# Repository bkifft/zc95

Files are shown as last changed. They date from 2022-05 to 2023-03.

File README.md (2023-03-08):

# ZC95

## Introduction
The ZC95 is a DIY four channel EStim box with similar form factor & output design to the MK312-BT (which in turn is a clone of the ET-312B).
Unlike the 312B, it uses 2x Raspberry Pico microcontrollers instead of an ATMEGA16, and the firmware is open source and mostly written in C++.

If a Pico-W is used for the main MCU, it can be controlled remotely via a Python GUI, and run Lua scripts uploaded to it.

Compared to an MK312-BT, it has 2 extra channels, two trigger inputs (think predicament bondage), and an accessory port. It is missing bluetooth and, _so far_, most of the patterns of the 312. Audio input is possible with an extra/optional board.

Additionally, if a 433MHz transmitter is fitted it can be used to control certain types of shock collars from some patterns.

It's mostly built using through hole parts, with one PCB being mostly SMD - but using parts available through the JLCPCB SMT assembly service. The only exception to this is the ADC for the front panel which is a SOIC-16 footprint so should still be easy enough for most to solder.

### Assembled ZC95
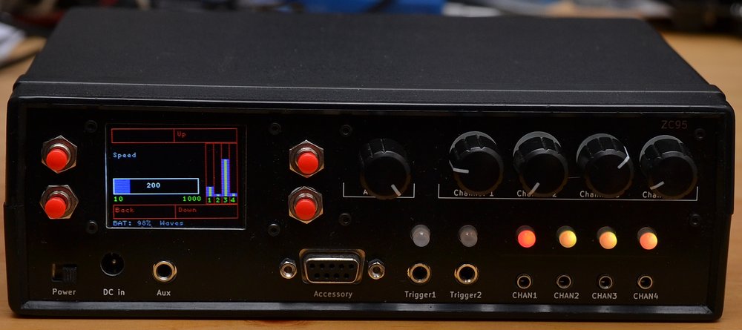
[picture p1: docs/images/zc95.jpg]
zc95


## Overview
The ZC95 consists of 4-5 PCBs:

* Front panel - no traces, just text / mounting holes
* Front panel controls - 4x POTs and associated ADC, 1x rotary encoder and 6 serial RGB LEDs
* Main board - power supply / charging, MCU for display / pattern generation, button input etc
* Output board ("ZC624 Output module") - 4 channel output generation controlled via SPI from the main board. Designed for production using the SMT assembly service at JLCPCB, with a handful of extra through hole parts also requiring hand soldering.
* (Optional) audio input board - allows the 3.5mm "Aux" port on the front panel to be used for audio input

The primary reason for having separate PCBs for the main and output board is for future flexibility - most of the time & expense is the firmware, case, display, controls, etc., so being able to test new output designs whilst being able to keep all of that should be an advantage. I'm well aware the output design currently used is known to have flaws, mostly stemming from its lack of feedback (which applies equally to the 312b it was taken from). A challenge for another day.

## [Build guide](docs/Build.md)

## [Schematics](schematics/)

## [Gerbers](pcb/)

## [Compiled firmware](https://github.com/CrashOverride85/zc95/releases/)

## [Operation notes](docs/Operation.md)

## [Pattern guide](docs/Patterns.md)

## [Lua scripting notes](docs/LuaNotes.md)

## [Credits](docs/Credits.md)

# TODO
## Firmware
   - Combo pattern? Having, e.g., waves on channels 1+2 plus something like TENS on 3+4 would be good
   - Save pattern settings on exit?

## Hardware
   - Maybe a better power switch? although still being able to get all the parts for the main board from LCSC is good
   - Low battery shutoff

## Long term road map
May do some of this, all of this, or none of this!
   - Combine main, output and audio boards into one, and probably switch to almost all SMD so it can be assembled by JLCPCB
   - Probably remove "Aux" socket and swap for separate "Serial" and "Audio" sockets
   - Use a lithium battery pack instead of a 12v SLA
   - Use a USB charger
   - Maybe a smaller, 3D printed case. Probably keeping the same width/weight though

## Known issues
   - Battery gauge is pretty hopeless
   - Depending on the pattern, the LEDs aren't very useful - either Red or Green, with no dimming depending on power

[zc95]: docs/images/zc95.jpg "Assembled ZC95"

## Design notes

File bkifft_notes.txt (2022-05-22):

made changes:
- used max232 with its 1 uF charge pumps

planned changes:
- use mk312 buttons
- change 12V rail to 13.3 V to use a 3s?p liion battery

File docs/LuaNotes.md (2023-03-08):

# Lua

## Capability
Lua scripts can be written / uploaded (see [Remote Access](./RemoteAccess.md) for how to upload) to add new patterns to the ZC95. These scripts are able switch each channel on/off, set the frequency and pulse width, and set the power level (scaled to what the front panel is set to - i.e. a Lua script can't set the output power to higher than set on the front panel).
They can also receive notification of settings being changed via the menu, and inputs from the external trigger inputs along with the top left soft button being pressed.
The most significant thing they can't do (that inbuilt patterns can) right now is anything to do with audio.

## Example scripts
There are a few example scripts in `remote_access/lua`, which demonstrate some of things that can be done from Lua. These scripts are:

* fire.lua - If the soft button is pressed, all channel's are activated for as long as the button is held down. If any of the 4 external triggers (assuming stereo connectors are being used), the the corresponding channel (1-4) is activated for as long the trigger is active.

* toggle.lua - switches between channel 1+2 & 3+4 at a speed that can be set via the menu. If the channels are switched on constant or just pulsed can also be set from the menu

* waves.lua - a waves pattern that is slightly more advanced than the inbuilt one. For each channel, this varies the frequency between 25Hz and 250Hz and the pulse width between 40us and 200us, with the time taken for each cycle being set per channel on the menu.

## toggle.lua

It's probably easier to explain Lua as implemented in the ZC95 by going though one of the example scripts.

toggle.lua:
```
_delay_ms = 500

Config = {
    name = "Toggle",
    menu_items = {
        {
            type = "MIN_MAX",
            title = "Delay",
            id = 1,
            min = 100,
            max = 2000,
			increment_step = 100,
            uom = "ms",
			default = _delay_ms
         },
         {
            type = "MULTI_CHOICE",
            title = "Output",
            id = 2,
            choices = {
                {choice_id = 1, description = "Pulse"},
                {choice_id = 2, description = "Constant"}
            }
         }
    }
}

_channel12_on = false
_wait_until_ms = 0
_pulse_mode = true

function MinMaxChange(menu_id, min_max_val)
    if (menu_id == 1)
    then
        _delay_ms = min_max_val
    end
end

function MultiChoiceChange(menu_id, choice_id)
    if (menu_id == 2 and choice_id == 1)
    then
        _pulse_mode = true
    end

    if (menu_id == 2 and choice_id == 2)
    then
        _pulse_mode = false
    end
end

function Loop(time_ms)
    if (time_ms > _wait_until_ms)
    then
        ToggleChannel();
        _wait_until_ms = time_ms + _delay_ms
    end
end

function ToggleChannel()
    if (_channel12_on == true)
    then
        zc.ChannelOff(1)
        zc.ChannelOff(2)

        if (_pulse_mode == true)
        then
            zc.ChannelPulseMs(3, 100)
            zc.ChannelPulseMs(4, 100)
        else
            zc.ChannelOn(3)
            zc.ChannelOn(4)
        end
        _channel12_on = false
    else
        if (_pulse_mode == true)
        then
            zc.ChannelPulseMs(1, 100)
            zc.ChannelPulseMs(2, 100)
        else
            zc.ChannelOn(1)
            zc.ChannelOn(2)
        end

        zc.ChannelOff(3)
        zc.ChannelOff(4)
        _channel12_on = true
    end
end
```

The `Config` section is used to set the name and build the on screen menu:
```
Config = {
    name = "Toggle",
    menu_items = {
        {
            type = "MIN_MAX",
            title = "Delay",
            id = 1,
            min = 100,
            max = 2000,
			increment_step = 100,
            uom = "ms",
			default = _delay_ms
         },
         {
            type = "MULTI_CHOICE",
            title = "Output",
            id = 2,
            choices = {
                {choice_id = 1, description = "Pulse"},
                {choice_id = 2, description = "Constant"}
            }
         }
    }
}
```
`name = "Toggle"` sets the name for the script - this is prefixed with `U:` then used on the patterns menu.

A menu entry is displayed when the script is running for each item in `menu_items`; each must be given a unique id, numbered sequentially from 1. There are two types supported:
* `MIN_MAX` - shows a horizontal bar graph that can be changed between the set min/max using the adjust dial. The unit of measure (uom) text is displayed as suffix to the numeric value in the bar chart 
* `MULTI_CHOICE` - used to show a menu option that allows for one of multiple settings to be picked. Each choice must have a unique id.

```
function MinMaxChange(menu_id, min_max_val)
    if (menu_id == 1)
    then
        _delay_ms = min_max_val
    end
end
```
If present, the `MinMaxChange(menu_id, min_max_val)` function is called whenever a `MIN_MAX` menu type is changed, with the ID of the menu and the new value.

```
function MultiChoiceChange(menu_id, choice_id)
    if (menu_id == 2 and choice_id == 1)
    then
        _pulse_mode = true
    end

    if (menu_id == 2 and choice_id == 2)
    then
        _pulse_mode = false
    end
end
```
Similar to MinMaxChange but for `MULTI_CHOICE` menu types; if present, the `MultiChoiceChange(menu_id, choice_id)` function is called whenever a `MULTI_CHOICE` type menu entry is changed, with the menu ID and the choice ID now selected.

```
function Loop(time_ms)
    if (time_ms > _wait_until_ms)
    then
        ToggleChannel();
        _wait_until_ms = time_ms + _delay_ms
    end
end
```
The `Loop(time_ms)` function is mandatory, and is called periodically for as long as the Lua script is running. The time_ms parameter is how long, in milliseconds, since the box was powered up.

```
function ToggleChannel()
    if (_channel12_on == true)
    then
        zc.ChannelOff(1)
        zc.ChannelOff(2)

        if (_pulse_mode == true)
        then
            zc.ChannelPulseMs(3, 100)
            zc.ChannelPulseMs(4, 100)
        else
            zc.ChannelOn(3)
            zc.ChannelOn(4)
        end
        _channel12_on = false
    else
        if (_pulse_mode == true)
        then
            zc.ChannelPulseMs(1, 100)
            zc.ChannelPulseMs(2, 100)
        else
            zc.ChannelOn(1)
            zc.ChannelOn(2)
        end

        zc.ChannelOff(3)
        zc.ChannelOff(4)
        _channel12_on = true
    end
end
```

The `ToggleChannel()` function (could have been named anything) is switching between the two pairs of channels. The relevant parts are the zc.* functions:
* `zc.ChannelPulseMs(channel, duration)` - will pulses a channel on for the specified number of milliseconds
* `zc.ChannelOn(channel)` - switches a channel on until switched off
* `zc.ChannelOff(channel)` - switches a channel off

See zc.* functions section below for more details along with all available zc.functions

## zc.* functions
Functions that can be called from Lua scripts to control the box. In addition to these, `print("<whatever>")` can be used from scripts (no `zc.` prefix); the output will appear in the serial output prefixed with '`[LUA]`', and in the debug window of the `pattern_gui.py` GUI if running remotely. 

### SetPower
```
Params:
    * channel - 1-4
    * power   - 0-1000
```
Sets the output power of channel from 0 to 1000. This output power is scaled based on what the front panel dial is set to for the channel. E.g if the front panel is set to 50% and a power level of 500 is set, the result will be a power level of 250 (25%).

If there is no `Setup()` function in the script, all channels will default to full power (i.e. only affected by front panel dials), so it often isn't necessary to use this. Most inbuilt patterns don't change the power level.

### SetFrequency
```
Params:
    * channel number (1-4)
    * frequency (1 - 300) Hz
```
Sets the output frequency of the specified channel. Currently defaults to 150Hz, but this default may move into the config menus at some point.

### SetPulseWidth
```
Params:
    * channel number (1-4)
    * positive pulse width (1-255) us
    * negative pulse width (1-255) us
```
Sets the pulse width used for the channel, defaults to 150us, but this default may move into the config menus at some point.
For symmetric pulses (as used by most/all inbuilt patterns), these two values should be the same. 

### ChannelPulseMs
```
Params:
    * channel number (1-4)
    * duration (ms)
```
Switch the channel on for the specified number of milliseconds, using the previously set frequency, pulse width and power level (or the defaults, if not changed).

### ChannelOn
```
Params:
    * channel number (1-4)
```
Switch on the specified channel, until ChannelOff is called, using the previously set frequency, pulse width and power level (or the defaults, if not changed).

### ChannelOff
```
Params:
    * channel number (1-4)
```
Switch off the specified channel.

## Special functions
These are functions that will be automatically called when applicable whilst the Lua script is running. With the exception of `Loop()`, all are optional. 

### MinMaxChange(menu_id, new_value)
Called when a `MIN_MAX` type pattern option is changed, and is called with the menu ID of the option, and the new value (which should lie between the min and max configured).

### MultiChoiceChange(menu_id, choice_id)
Called when a `MULTI_CHOICE` type pattern option is changed, and is called with the menu ID of the option, and the ID of the selected choice.

### SoftButton(pushed)
Called with `pushed=True` when the top left soft button is pressed, and then again when it is released with `pushed=False`.

### ExternalTrigger(socket, part, active)
Called when an external trigger happens.

Socket: can be either "`TRIGGER1`" or "`TRIGGER2`" for the Trigger1 and Trigger2 sockets respectively. 

Part: can be either "`A`" or "`B`". With a stereo 3.5mm TRS cable inserted, shorting Tip and Sleeve is part `A` (trigger LED lights up green). Shorting Tip and Ring is part `B` (trigger LED lights up red). When triggered, `active` will `True`, when released it will be `False`.

### Setup
Called once when the pattern is started, before `Loop()`. It can be used to do any initial setup, including setting power level. If this function does _not_ exist, the power level is defaulted to 1000, otherwise it is set to 0 and can be set to something more appropriate here. 

### Loop(time_ms)
Called periodically for as long as the pattern is running. `time_ms` is how long in milliseconds the box has been powered on.

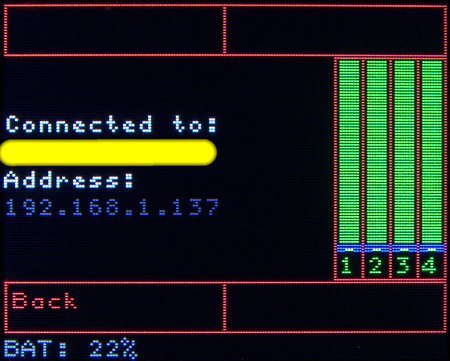
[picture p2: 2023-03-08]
docs/images/screen_ra_connected.jpg

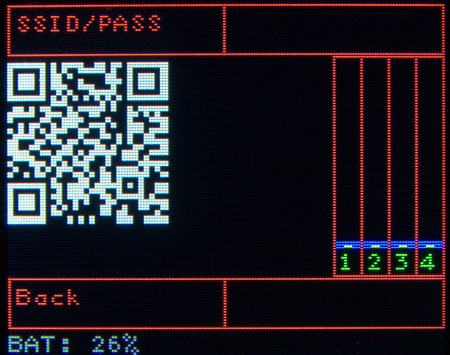
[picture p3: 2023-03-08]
docs/images/screen_ra_qr.jpg

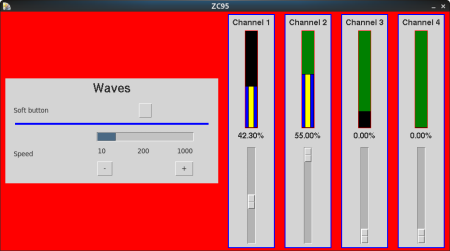
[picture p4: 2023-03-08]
docs/images/pattern_gui_start.png

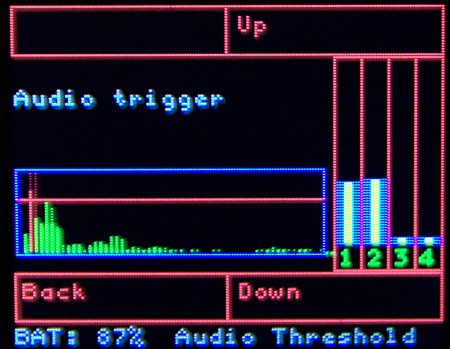
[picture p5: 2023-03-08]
docs/images/screen_pattern_audioThreshold.jpg

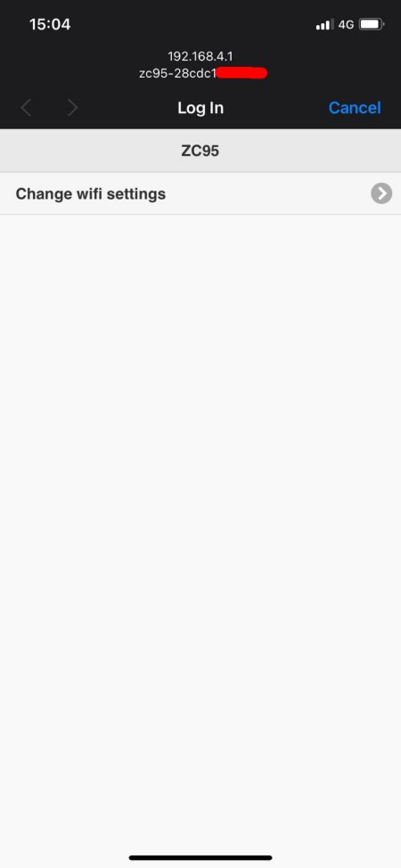
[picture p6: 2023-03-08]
docs/images/phone_config_wifi.jpg

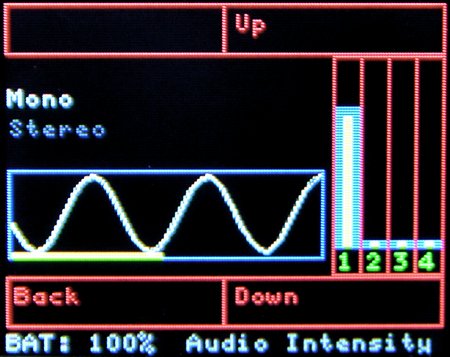
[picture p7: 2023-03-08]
docs/images/screen_pattern_audioIntensity.jpg

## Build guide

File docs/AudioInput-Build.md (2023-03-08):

# Hardware build notes for audio input board

## Changes to ZC95 main board
Two changes are required:
  1. Remove the jumpers on J8
  2. Fit a 10 way 2.54mm pin header on J17

## Ordering
Parts required for this board are on the "Audio input" tab of the [BoM (openoffice format)](BoM.fods) spreadsheet. 
When building the board, there are two choices for gain control:

1. Internal adjustment only - fit RV1 and RV2
2. (Recommended) Variable from menu - Fit U1. Also allows the presence of the board to be auto-detected

The downside of fitting U1 is cost, plus it's an SMD part (and whilst not hard, it's also not the easiest part to solder if you've never done anything SMD before). Also it's the sort of part that might go out of stock at any moment...

Order the blank PCB from JLC using the [AudioInput](../pcb/AudioInput.zip) gerbers and the default settings (FR-4, 1.6mm thick, 1oz, etc.)

## Assembly notes

Unfortunately I didn't manage to fit the component values on the silkscreen, so the best way to assemble the board is probably just going through the BoM which lists component references & values; a printout of the [board outline and silkscreen](./AudioOutput.pdf) may help.

Mistake on silkscreen: the footprints for Q1 & Q3 (P Channel MOSFETs) are backwards if ordering the LCSC part C151450. If ordering the part from elsewhere be aware that BS250 MOSFETs come in two different pinouts - DGS and SGD, so putting the part in backwards is rather easy! Perhaps a poor choice of mosfet by me there.
The most practical solution is probably just to use a diode tester on the actual part, and put the anode on the left when inserting it (assuming the board is orientated with the version text the right way up at the bottom).

Assembled board:

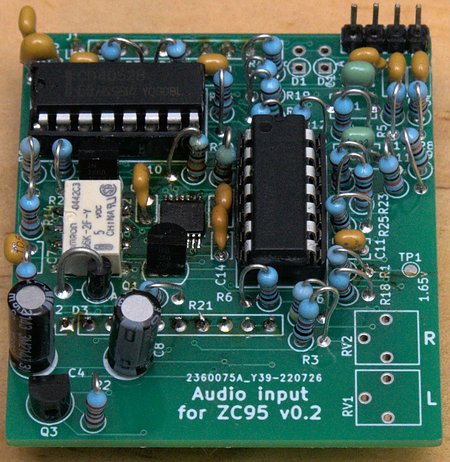
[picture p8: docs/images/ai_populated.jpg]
AI board


Once assembled, plug the audio board into the main board, with the text ("Audio input for ZC95") towards the front / near the front panel. Be careful to line it up correctly with the headers, it is possible to insert it misaligned. 

If the digipot was fitted (U1) it should "just work", and the audio pattern(s) and "Audio input" menu should appear. If it wasn't fitted use the hardware config menu (see [audio operation notes](./AudioInput-Operation.md)) to set the Audio to "On (no gain)".

## Brief description
Hopefully not needed for the assembly & use of the board, but maybe a few notes about what this board is doing is good idea.

Without the board fitted, the jumpers fitted to J8 on the main board send the RS232 output from the UT232A IC to the 3.5mm "Aux" socket on the front panel. With the board fitted, the relay can be used to switch the Aux socket between the UT232A, and (ultimately) the ADC inputs present on header J1.

This somewhat shoddy diagram shows a high level overview of what's going on:

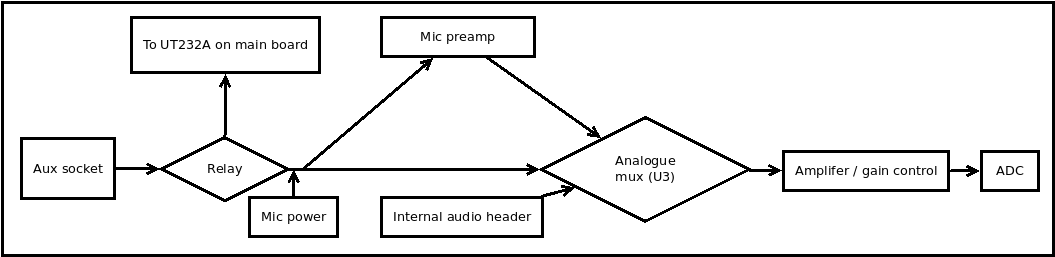
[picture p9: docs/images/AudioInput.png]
AI diagram


The firmware uses the presence of the digipot (U1, used for gain control) to detect the board and show the audio options. But this can be overridden from the Hardware Config menu, see [audio operation notes](./AudioInput-Operation.md).

One more thing maybe worthy of note is microphones... as this is an area where I didn't know what I didn't know!

There seem to be two common types of microphones (ignoring expensive stuff):

1. Electret microphones - typical PC style mics, including lavalier mics. These either require a small amount of power supplied to operate (in the region of 2v - 5v), or are self powered and need batteries / charging. Google suggests that electret mics generally have this bias power power on the ring, with signal on the tip. But of the two I tested, they both needed power on the tip. So like the mk312bt, this board also supplies power on tip+ring when enabled. There seem to be a few pinouts to consider when you get into stereo mic inputs, combined headset + mic inputs (4 conductor jacks), etc.

2. Dynamic microphones - think a hand held karaoke mic, that sort of thing. Produce a weaker signal than electret mics, but require no power (**and power could damage them**). Typically have a 6.35mm jack, but not always.

This audio input board works best with electret mics - there's not quite enough gain for dynamic mics - although R9 & R10 in the mic preamp could almost certainly be adjusted to make them work well enough.

[AI board]: images/ai_populated.jpg "Assembled audio input board"
[AI diagram]: images/AudioInput.png "Audio input diagram"

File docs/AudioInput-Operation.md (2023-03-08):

# Audio Input

If the (optional) audio input board is present, an extra "Audio input" option shows on the settings menu, along with patterns using audio input.

Audio input can be either line level or mic level (selectable), and optionally power can be provided for mics. It's intended to be used with PC style electret microphones. I've found this microphone works particularly well (and with the mk312bt): https://www.amazon.co.uk/gp/product/B07L6H7YYQ/

When the audio input board is installed, the Aux port on the front can be configured for either Audio input (default) or serial I/O (currently only debug out).

## Configuration
There are two relevant menus for configuring audio - "Audio input" and "Hardware config" ("Audio" and "Aux port use").

### Audio input
This is used to set gain, enable/disable microphone preamp (so set for mic or line level), enable/disable microphone power, and show a preview of the audio signal to aid setting volume and gain.
The configuration set here will be used in patterns, and will be retained after power off. 

On opening the screen, it should show the currently configured settings. E.g.:

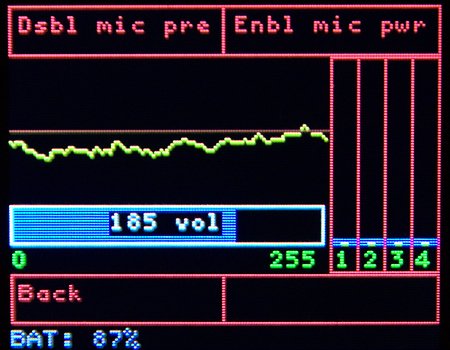
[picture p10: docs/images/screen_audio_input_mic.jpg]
Audio input mic


The above screenshot is when in microphone mode, with the microphone power disabled (using a self powered electret mic). Options:
* Ddbl mic pre: Disable microphone preamp - i.e. switch to line level input
* Enbl mic pwr: Enable microphone power - provide power for an unpowered electret microphone. Note this should not be used with dynamic mics or when connected to a line level output

Disabling the mic preamp switches to line level input, and shows stereo input:

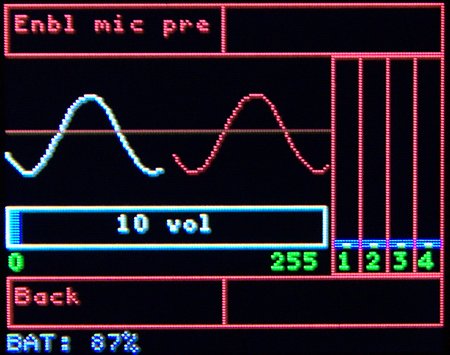
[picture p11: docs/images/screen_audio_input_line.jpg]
Audio input line


### Hardware config
There are two relevant entries in the hardware config menu:

1. Audio. 
This is used to control audio functionality, and has 3 options
    - Auto - Default. If the audio output board is detected (specifically, if the MCP4651 digital potentiometer is found), then audio functionality is enabled, otherwise it's hidden.
    - On (no gain) - Audio input functionality is enabled regardless of the audio board being detected or not. But the gain/volume option is removed, as that requires the digital potentiometer to be present.
    - Off - hide audio functionality even if audio input board found

2. Aux port use. 
With the audio board present, the zc95 has the ability to switch the use of the port between serial I/O and audio input. At present, the only use for the serial option is outputting debugging info, but in the future some patterns may make use of it. Two options:
    - Audio input - Default. Port is used for audio input
    - Serial I/O - port is used for serial I/O

Note this option has no effect if the audio input board isn't present; the port is always routed to the serial interface.

[Audio input mic]: images/screen_audio_input_mic.jpg "Audio input configuration screen - mic"
[Audio input line]: images/screen_audio_input_line.jpg "Audio input configuration screen - line input"

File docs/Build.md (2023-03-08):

# Hardware build notes 

*Disclaimer*: These instructions are complete to the best of my knowledge, however I've only built the one so far, and that was over quite some time, so there may be omissions.

There is now an optional audio [input board](./AudioInput-Build.md) too.

## Prerequisites 
These notes assume a reasonable amount of experience assembling electronic kits. Other than through hole soldering, it also requires:
* Soldering 1 SMD part on the front panel control board. This is a SOIC-16 package, so fairly large / easy to solder
* Creating an IDC cable
* Crimping connectors for Molex KK style (well, clones in this case) connectors. Other 2.54mm connectors could be substituted.

## PCB + Parts ordering
### PCBs
For these 3 boards, order from JLC using the linked gerbers and default settings (FR-4, 1.6mm thick, 1oz, etc.) except where noted:
* [Front panel](../pcb/FrontPanel.zip). Suggest ordering in black
* [Front panel controls](../pcb/FrontPanelControls.zip). Set "Remove Order Number" to "Specify a location" (location is already specified on the back of this board)
* [Main board](../pcb/MainBoard.zip)

The output board ("ZC624 Output module") has been designed with the JLCPCB SMT assembly service in mind, although the footprints are the hand-solder versions where applicable, and some (through hole) parts still need hand assembly.
Order the board using [these gerbers](../pcb/OutputModule/OutputBoard-gerbers.zip) and the default options as per the other boards.

This time, select the "SMT Assembly" option at the bottom - pick "Assemble top side" and Tooling holes "Added by JLCPCB". 
On the next page, add the BOM and CPL files:
* [output_bom_jlc.csv](../pcb/OutputModule/output_bom_jlc.csv)
* [output_cpl_jlc.csv](../pcb/OutputModule/output_cpl_jlc.csv)

The next page should show a list of all parts found / matched. Deselect the SS210 component (D8, D9, D10, D11, D12, D13, D14, D15), these aren't needed and reduce output power.

### PCB Parts
All parts required to populate the PCBs - with the exception of the transformers - can be purchased from LCSC, and this BOM spreadsheet lists required parts + quantity with the LCSC part number for each board on separate tabs:

[BoM (openoffice format)](BoM.fods)

As with the MK312-BT, the PFETs (IRF9Z24NPBF) in particular should not be substituted with anything similar, the exact part should be used.

### Misc parts
[The BoM spreadsheet](BoM.fods) includes a Misc tab with the rest of the parts required to complete the build (case, display, etc.).

## Assembly

### Main board
Photo of board as it arrived from JLCPCB:

main board

* Be sure not to mix up U3 (LM2941T, top left) and U6 (LM2576T-5, top middle), these have the same footprint and quite similar names
* Fit the IC sockets (if ordered) instead of directly soldering the ICs to the board
* J8 should have jumpers between pins 1+2, 3+4, 7+8, 9+10, like so:

  jumpers

  Without these the serial port on the front won't work (but it won't affect anything else).
* Solder short (~12cm or so) wires on to J13, and fit spade connectors on the other end for the battery
* R14 & D4 (top middle) don't need to be populated. It's for a power LED that has no place on the front panel.
* J20 (I2C header, bottom left) is for future expansion and doesn't need to be populated
* J17 (just below battery, to the right) is for the optional audio input board; if building that, fit a 2.54mm pin header, otherwise leave unpopulated

Then (optionally) plug a 433MHz transmitter into J11

Populated board:

main board populated

### Output board ("ZC624 Output module")
Photo of board as it arrived from JLCPCB:

zc624 smt only

D8-D15 are populated in this photo, but these should be omitted when ordering the boards (or removed if ordered by mistake), as they reduce output power.

Notes
* The pin headers J1, J2 & J3 go on the bottom of the board, J4 ("Serial") on the top. I found it easier to plug the board into the main board, then solder J1, J2 & J3 to be sure they were straight / lined up
* The 4 transformers have the "P" facing inwards (towards each other). Note that the transformers are used "backwards" - the side labelled primary goes to outputs.
* PFETs Q2, Q5 & Q8 should have the metal back facing towards the bottom (transformer end) of the board. Q11 is the other way round (silkscreen is correct)
* Solder on both the 1x20 pin sockets for the Pico. The 3 pin header on the right should be unpopulated.

Fully assembled board:

zc624 populated

### Front panel controls 
Photo of board as it arrived from JLCPCB:

front panel controls-bottom
front panel controls-top

* All resistors are 10k, with the exception of R29 which is 100R (R29 is also the only resistor with its value labelled)
* Getting the LEDs at the correct height can be a little awkward. Suggest soldering the POTs + rotary encoder first, putting the LEDs in (no solder yet), then attaching the board to the front panel (using 20mm bolts). Make sure the LEDs are level-ish, then solder in place.
* Stating the obvious, but put the parts on the side indicated by the silkscreen (LEDs, POTs and rotary encoder one side, the rest the other)
* J1 should have the cut-out facing towards SW5 (rotary encoder)

Fully assembled board:

front panel controls-bottom-populated
front panel controls-top-populated

### Front panel
Photo of board as it arrived from JLCPCB:

front panel

* Perhaps the most annoying part of the whole build is creating a cable for the 4 buttons. The buttons are named like so:

front panel buttons

Wire each button back to a connector in the position that matches the silkscreen (first two positions are button A, next two button B, etc.)
Then attach the buttons to the front panel.

* Attach connector to back of LCD, then LCD to the front panel with M2, 12mm bolts

The board should look something like this:

front panel back

Finally, attach the front panel controls board using 20mm bolts. The completed assembly should look something like:

front panel assembled

### Miscellaneous
* Create a 10pin F-F cable for the display:

10pin F-F cable

(ok, so that looks pretty messy, but it works)

* Create a 2x4 way IDC cable for the front panel controls to main board:

8w IDC

* Push the front panel (with controls board already attached) onto the main board, then screw on the DB9 socket:

front panel attached to main

* Slot the boards into the case, and screw in place: Screw Length (Excluding Head): 1/4" (6.5mm), Screw Size: No.6 (3.5mm)

* Stick the battery down. Suggest using 3M double sided tape (MNT-FT24MM-16FT)

* Connect front panel to main board using IDC cable

* Connect LCD to main board using 10pin cable

* Copy main board firmware onto first Pico, or a Pico W if wanting remote access (see section below), then plug into main board (USB socket pointing towards the left / nearest case edge)

* Copy ZC624 firmware onto second Pico (see section below), then plug into ZC624 board (USB socket pointing towards the left)

* Plug the ZC624 into the main board. Be careful to line it up correctly as it is possible to plug it in misaligned which would be bad

* Connect battery

Assembled ZC95 should look like:

zc95 assembled

### Loading firmware
Download firmware from [Releases](https://github.com/CrashOverride85/zc95/releases).

To load firmware onto a Pico:
* Hold down the BOOTSEL button
* Connect to PC via USB
* The Pico should appear as a USB mass storage device. Drag the appropriate uf2 firmware binary onto the drive:
  - zc95.uf2 - Main board firmware
  - OutputZc.uf2 - ZC624 firmware

And don't mix the two up!

### Power up
On power up, the LEDs should briefly turn purple (~2s), then turn green as the screen switches on and shows:

zc95 powered up

# Debugging
If any of the I2C devices aren't detected, you should see an error similar to the below:

hw check fail

Here, it can't find the two ICs on the front panel (in this case, the IDC cable was unplugged).
There is serial debugging output on the "Accessory" DB9 connector (tx pin 3, ground pin 5) on the front panel at RS232 levels.

There is also debugging output from the ZC624 board on the serial header. Note that is at 3v3 level, and RS232 levels would damage it. 

[jumpers]: images/jumpers.jpg "J8 with jumpers fitted"
[main board]: images/main_board.jpg "Unpopulated main board"
[main board populated]: images/main_board_populated.jpg "Populated main board"
[zc624 smt only]: images/zc624.jpg "ZC624 as received from JLCPCB"
[zc624 populated]: images/zc624_populated.jpg "Fully populated ZC624"
[front panel controls-bottom]: images/fpc_bottom.jpg "Unpopulated front panel controls board - bottom"
[front panel controls-top]: images/fpc_top.jpg "Unpopulated front panel controls board - top"
[front panel controls-bottom-populated]: images/fpc_bottom_populated.jpg "Populated front panel controls board - bottom"
[front panel controls-top-populated]: images/fpc_top_populated.jpg "Populated front panel controls board - top"
[front panel]: images/fp.jpg "Front panel"
[front panel buttons]: images/fp-abcd.jpg "Front panel with buttons labelled"
[front panel back]: images/fp_back.jpg "Back of front panel with LCD and buttons attached"
[front panel assembled]: images/fp_assembled.jpg "Front panel with LCD, buttons and controls attached"
[10pin F-F cable]: images/10pinFF.jpg "10 pin F-F cable"
[8w IDC]: images/8w_idc.jpg "2x4 IDC cable"
[front panel attached to main]: images/fp_attached_to_main.jpg "Front panel attached to main board"
[zc95 assembled]: images/assembled.jpg "Fully assembled ZC95, minus cover"
[zc95 powered up]: images/powered_up.jpg "Fully assembled ZC95 powered up"
[hw check fail]: images/hw_check_fail.jpg "Power up error"

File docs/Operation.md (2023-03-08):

# Operation

## Device layout
device layout

Buttons 1 - 4 are soft buttons and the purpose changes dependant on the screen. 

| Number | Description
| --- | ---
| 1 | Softbutton - Used to select pattern from the main menu, and changes dependant on the selected pattern.
| 2 | Softbutton - Usually back / return to previous screen
| 3 | Softbutton - Usually scroll up
| 4 | Softbutton - Usually scroll down
| 5 | Power. Left is off, right is on. Probably should have labelled that.
| 6 | Power in. Should be centre positive 15v DC
| 7 | Either Serial port, or if optional audio input board fitted, can be toggled between serial and audio input. In serial mode, Tip is TX / output from box, Sleeve is ground.
| 8 | Accessory port. Includes power, serial and 3x GPIO pins. See "Accessory port" in misc section. Currently not really used by much.
| 9 | Trigger input 1. Shorting either Sleeve or Ring to Tip registers trigger. The box can differentiate between S-T and R-T triggers (i.e. each trigger socket can react to two different inputs)
| 10 | Trigger input 2. As above, except currently unused.
| 11 | 2.5mm socket for channel 1 output
| 12 | 2.5mm socket for channel 2 output
| 13 | 2.5mm socket for channel 3 output
| 14 | 2.5mm socket for channel 4 output
| 15 | Adjust - Used to change the setting of on-screen sliders / multi choice options. A blue bar/background in the middle/left section of the screen indicates when the Adjust control can be used
| 16 | Power control for channel 1
| 17 | Power control for channel 2
| 18 | Power control for channel 3
| 19 | Power control for channel 4
| 20 | LED indicator for trigger 1. Lights up when triggered
| 21 | LED indicator for trigger 2. Lights up when triggered
| 22 | LED indicator for channel 1. Green = Internal channel 1 selected, but no output. Yellow = Shock collar 1 selected - see config section - but no output (2.5mm CHAN1 unused). Red = output on (either 2.5mm output or shock collar, depending on config)
| 23 | As above, but for channel 2 
| 24 | As above, but for channel 3
| 25 | As above, but for channel 4

## Screen
screen layout

| Number | Description
| --- | ---
| 1 | Softbutton - Text for softbutton 1
| 2 | Softbutton - Text for softbutton 2 
| 3 | Softbutton - Text for softbutton 3
| 4 | Softbutton - Text for softbutton 4
| 5 | Menu items. White text is the currently selected option
| 6 | Option corresponding to selected menu item. Can be changed using the Adjust dial
| 7 | Current power level for each channel. The blue bar represents the current maximum power the pattern can use, as set by the power control dials. The yellow bar inside it shows the current power level the patten is using. For most patterns, these will be the same, but some (e.g. triggered climb) will have a much smaller (but rising) yellow bar.

## On power up
On first power up, the box shows a menu of available patterns. Either the highlighted pattern can be started by pressing soft button 1, or the config menu can be entered by using soft button 2.

## Config
Configuration options so far:

* Remote access - Only visible if running on a Pico-W. Allows for remote access to the ZC95 over WiFi, for the purpose of either remotely controlling it or uploading Lua scripts. See [Remote Access](./RemoteAccess.md) 

* Channel config - For each channel 1-4, picks if either the internal output (on the 2.5mm connector) should be used, or if a shock collar should be triggered

* Collar config - Allows 4x shock collars to be configured. Each shock collar needs to be paired to the box, and the bottom option allows for testing the collar with the current settings. The "Chan." option corresponds to the CH button on the original remote, and it probably makes sense to be left as 1 for all collars, as each will have a unique ID anyway. Note that the mode (shock / vibrate / beep) needs to be set here, and won't change outside of this config screen (for the time being, at least)

* LED brightness - Pretty much what it says. If you value your eyesight, single digit values are good.

* Ramp up time - When starting a pattern, how long it takes to ramp up to the power level set for the channel on the front panel

* Audio input - Displayed if audio board present by default, depends on "Hardware config > Audio" setting. See [Audio Input](./AudioInput-Operation.md)

* Hardware config - configure various hardware settings. Shouldn't need changing. Options:
  - Audio - control display of audio options. See [Audio Input](./AudioInput-Operation.md) 
  - Debug output - where debugging information is sent:
    - Accessory port
    - Aux port
    - Off

    Note that if the Aux port is configured to be used for audio, picking Aux port here is essentially the same as "Off". Also worth noting that when the box is first powered up, debug info is always sent to the accessory port until the configuration is read, before potentially switching to aux or off.

  - Aux port use - what the Aux port on the front is used for. Options:
    - Audio input
    - Serial I/O

    If the audio board isn't present, this menu has no effect, i.e. Aux is always in Serial I/O mode.

* About - shows firmware version of main board, and zc624 output board

## Shock collars
If the box is fitted with a 433Mhz AM transmitter in J11 on the main board, it can be used to control one specific type of shock collar:

Shock collar

(note that there is 915MHz variant of these that looks identical on the outside...)

These will only function in certain patterns which have simpler output demands, and is generally pretty experimental.

[device layout]: images/layout.png "Device layout"
[screen layout]: images/screen.png "screen layout"
[shock collar]: images/shock_collar.jpg "Supported shock collar"

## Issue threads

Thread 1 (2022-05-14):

Missing i2c addresses in Frontpanel schematics

bkifft, 2022-05-14:

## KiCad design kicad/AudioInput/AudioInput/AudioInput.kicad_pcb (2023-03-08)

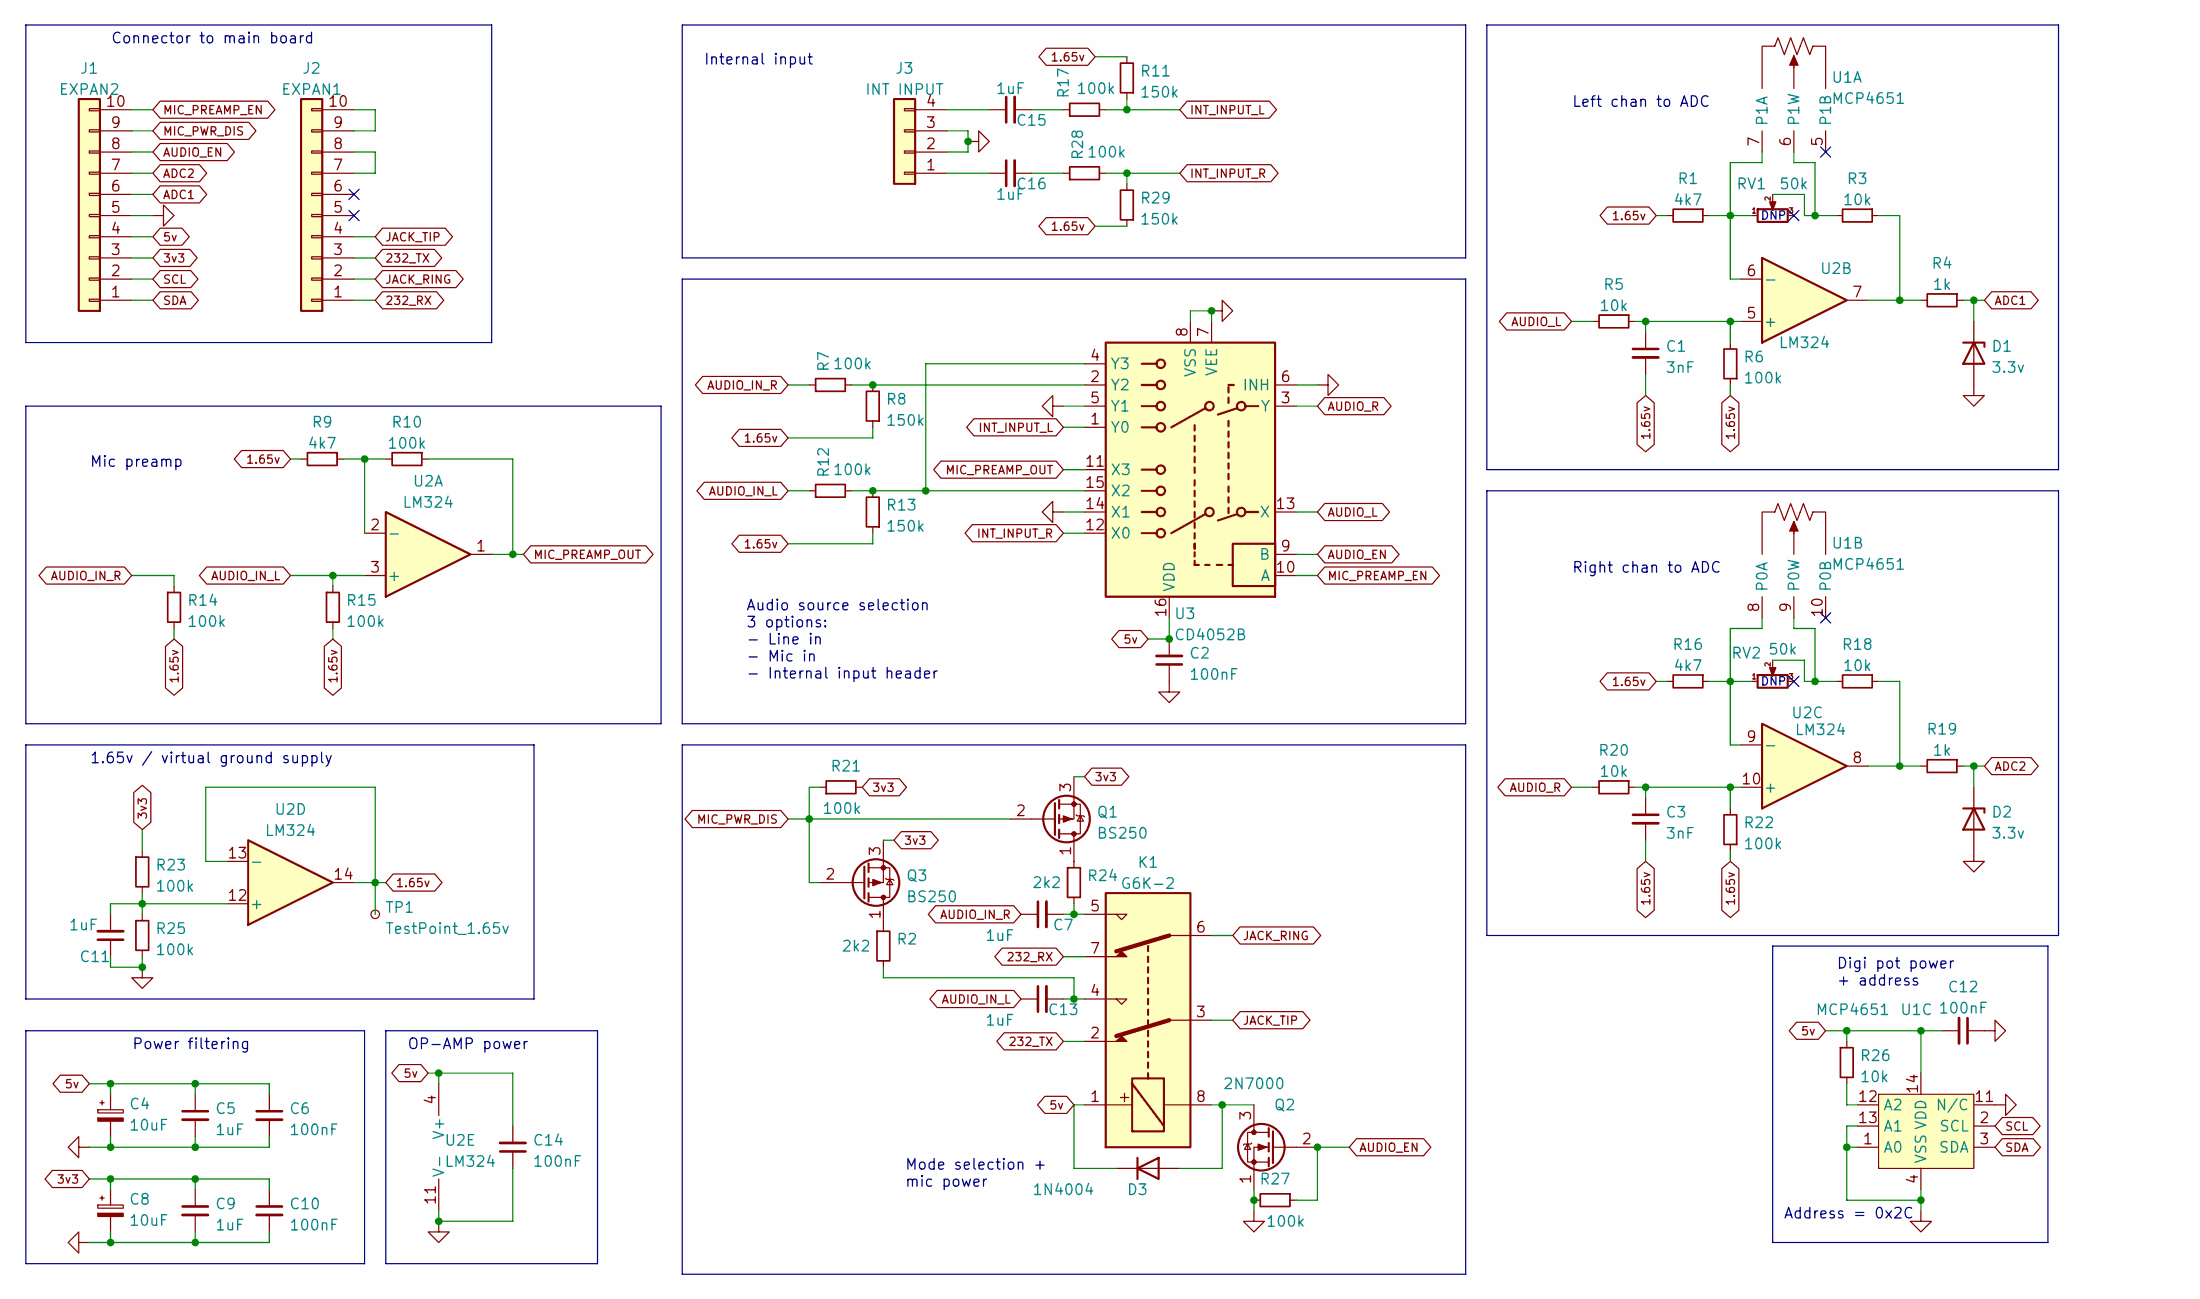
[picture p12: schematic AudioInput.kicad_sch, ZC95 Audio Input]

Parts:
C1, C3: 3nF; C_Disc_D5.1mm_W3.2mm_P5.00mm; LCSC C454433
C2, C6, C10, C12, C14: 100nF; C_Disc_D3.4mm_W2.1mm_P2.50mm
C4, C8: 10uF; CP_Radial_D5.0mm_P2.00mm
C5, C7, C9, C11, C13, C15, C16: 1uF; C_Rect_L4.0mm_W2.5mm_P2.50mm
D1, D2: 3.3v; D_DO-35_SOD27_P2.54mm_Vertical_AnodeUp; LCSC C125652
D3: 1N4004; D_DO-41_SOD81_P3.81mm_Vertical_AnodeUp
J1: EXPAN2; PinHeader_1x10_P2.54mm_Vertical
J2: EXPAN1; PinHeader_1x10_P2.54mm_Vertical
J3: INT INPUT; PinHeader_1x04_P2.54mm_Vertical
K1: G6K-2; Relay_DPDT_Omron_G6K-2F-Y
Q1, Q3: BS250; TO-92_Inline
Q2: 2N7000; TO-92_Inline
R1, R9, R16: 4k7; R_Axial_DIN0207_L6.3mm_D2.5mm_P2.54mm_Vertical
R2, R24: 2k2; R_Axial_DIN0207_L6.3mm_D2.5mm_P2.54mm_Vertical
R3, R5, R18, R20, R26: 10k; R_Axial_DIN0207_L6.3mm_D2.5mm_P2.54mm_Vertical
R4, R19: 1k; R_Axial_DIN0207_L6.3mm_D2.5mm_P2.54mm_Vertical
R6, R7, R10, R12, R14, R15, R17, R21, R22, R23, R25, R27, R28: 100k; R_Axial_DIN0207_L6.3mm_D2.5mm_P2.54mm_Vertical
R8, R11, R13, R29: 150k; R_Axial_DIN0207_L6.3mm_D2.5mm_P2.54mm_Vertical
RV1, RV2: 50k; 3362P-1-503
TP1: TestPoint_1.65v; TestPoint_Pad_D1.5mm
U1: MCP4651; TSSOP-14_4.4x5mm_P0.65mm
U2: LM324; DIP-14_W7.62mm_Socket
U3: CD4052B; DIP-16_W7.62mm_Socket

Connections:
1.65v: C1.2, C3.2, R1.2, R6.1, R8.1, R9.2, R11.2, R13.1, R14.2, R15.2, R16.2, R22.1, R29.1, TP1.1, U2.13 (-), U2.14
3v3: C8.1, C9.1, C10.1, J1.3, Q1.3 (S), Q3.3 (S), R21.2, R23.1
5v: C2.2, C4.1, C5.1, C6.1, C12.2, C14.2, D3.1 (K), J1.4, K1.1, R26.1, U1.14 (VDD), U2.4 (V+), U3.16 (VDD)
232_RX: J2.1, K1.7
232_TX: J2.3, K1.2
ADC1: D1.1 (K), J1.6, R4.1
ADC2: D2.1 (K), J1.7, R19.1
AUDIO_EN: J1.8, Q2.2 (G), R27.1, U3.9 (B)
AUDIO_IN_L: C13.1, R12.1, R15.1, U2.3 (+)
AUDIO_IN_R: C7.1, R7.1, R14.1
AUDIO_L: R5.2, U3.13 (X)
AUDIO_R: R20.2, U3.3 (Y)
GND: C2.1, C4.2, C5.2, C6.2, C8.2, C9.2, C10.2, C11.1, C12.1, C14.1, D1.2 (A), D2.2 (A), J1.5, J3.2, J3.3, Q2.1 (S), R25.2, R27.2, U1.1 (A0), U1.4 (VSS), U1.11 (N/C), U1.13 (A1), U2.11 (V-), U3.5 (Y1), U3.6 (INH), U3.7 (VEE), U3.8 (VSS), U3.14 (X1)
INT_INPUT_L: R11.1, R17.2, U3.1 (Y0)
INT_INPUT_R: R28.2, R29.2, U3.12 (X0)
JACK_RING: J2.2, K1.6
JACK_TIP: J2.4, K1.3
MIC_PREAMP_EN: J1.10, U3.10 (A)
MIC_PREAMP_OUT: R10.1, U2.1, U3.11 (X3)
MIC_PWR_DIS: J1.9, Q1.2 (G), Q3.2 (G), R21.1
unnamed: C1.1, R5.1, R6.2, U2.5 (+)
unnamed: C3.1, R20.1, R22.2, U2.10 (+)
unnamed: C7.2, K1.5, R24.2
unnamed: C11.2, R23.2, R25.1, U2.12 (+)
unnamed: C13.2, K1.4, R2.2
unnamed: C15.1, J3.4
unnamed: C15.2, R17.1
unnamed: C16.1, J3.1
unnamed: C16.2, R28.1
unnamed: J2.7, J2.8
unnamed: J2.9, J2.10
unnamed: D3.2 (A), K1.8, Q2.3 (D)
unnamed: Q1.1 (D), R24.1
unnamed: Q3.1 (D), R2.1
unnamed: R1.1, RV1.1, U1.7 (P1A), U2.6 (-)
unnamed: R3.1, R4.2, U2.7
unnamed: R3.2, RV1.2, U1.6 (P1W)
unnamed: R7.2, R8.2, U3.2 (Y2)
unnamed: R9.1, R10.2, U2.2 (-)
unnamed: R12.2, R13.2, U3.4 (Y3), U3.15 (X2)
unnamed: R16.1, RV2.1, U1.8 (P0A), U2.9 (-)
unnamed: R18.1, R19.2, U2.8
unnamed: R18.2, RV2.2, U1.9 (P0W)
unnamed: R26.2, U1.12 (A2)
SCL: J1.2, U1.2 (SCL)
SDA: J1.1, U1.3 (SDA)

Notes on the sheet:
Digi pot power + address
Mode selection + mic power
Internal input
DNP
Right chan to ADC
Address = 0x2C
1.65v / virtual ground supply
Mic preamp
OP-AMP power
Connector to main board
Power filtering
Audio source selection 3 options: - Line in - Mic in - Internal input header
Left chan to ADC

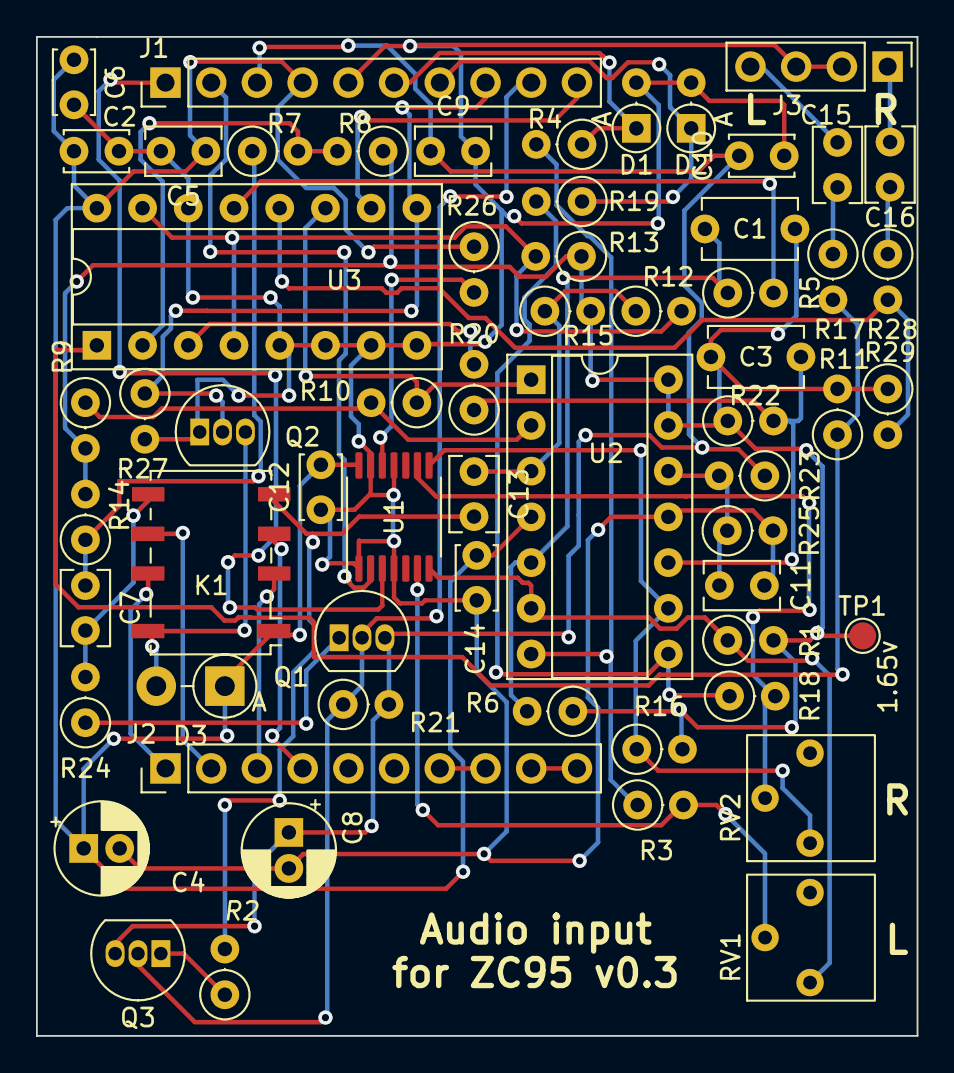
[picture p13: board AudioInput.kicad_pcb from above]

Board: 2 copper layers, 48.9 x 55.5 mm, 61 parts (0 on the bottom side), 46 nets.

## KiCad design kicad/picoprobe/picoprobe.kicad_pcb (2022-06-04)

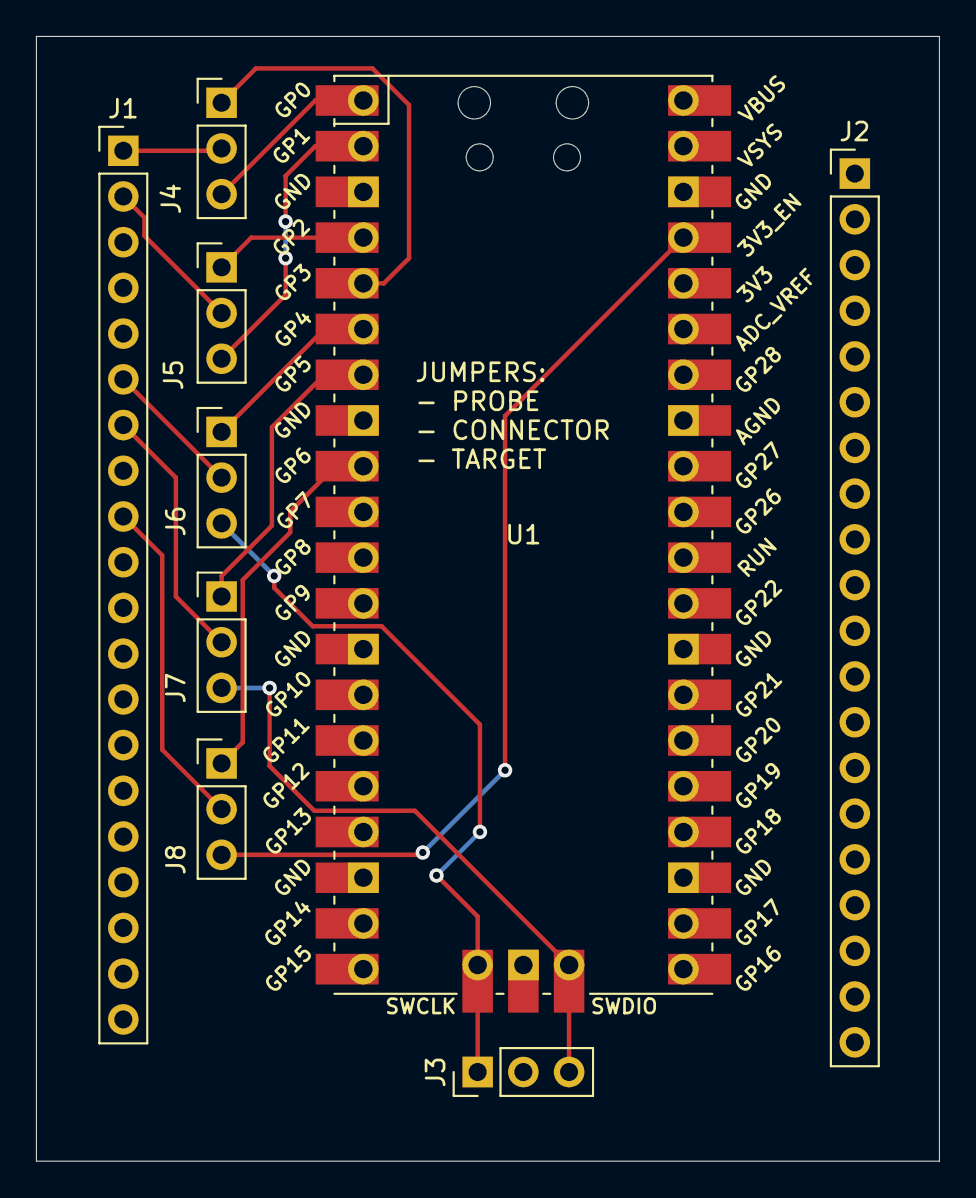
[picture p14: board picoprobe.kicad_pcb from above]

Board: 2 copper layers, 50.2 x 62.5 mm, 9 parts (0 on the bottom side), 16 nets.

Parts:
J1: Connector left; PinHeader_1x20_P2.54mm_Vertical
J2: Connector right; PinHeader_1x20_P2.54mm_Vertical
J3: SWD; PinHeader_1x03_P2.54mm_Vertical
J4: UART 1; PinHeader_1x03_P2.54mm_Vertical
J5: UART 2; PinHeader_1x03_P2.54mm_Vertical
J6: SWCLK; PinHeader_1x03_P2.54mm_Vertical
J7: SWDIO; PinHeader_1x03_P2.54mm_Vertical
J8: RST; PinHeader_1x03_P2.54mm_Vertical
U1: Pico; RPi_Pico_SMD_TH

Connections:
GND: J1.3, J1.8, J1.13, J1.18, J2.3, J2.8, J2.13, J2.18, J3.2, U1.3, U1.8, U1.13, U1.18, U1.23, U1.28, U1.33, U1.38, U1.42
RST: J1.9, J8.2
SWCLK: J1.6, J6.2
SWDIO: J1.7, J7.2
UART1: J1.1, J4.2
UART2: J1.2, J5.2
pro_rst: J8.1, U1.9
pro_rx: J5.1, U1.4
pro_swclk: J6.1, U1.6
pro_swdio: J7.1, U1.7
pro_tx: J4.1, U1.5
tar_rst: J8.3, U1.37
tar_rx: J4.3, U1.1
tar_swclk: J3.1, J6.3, U1.41
tar_swdio: J3.3, J7.3, U1.43
tar_tx: J5.3, U1.2

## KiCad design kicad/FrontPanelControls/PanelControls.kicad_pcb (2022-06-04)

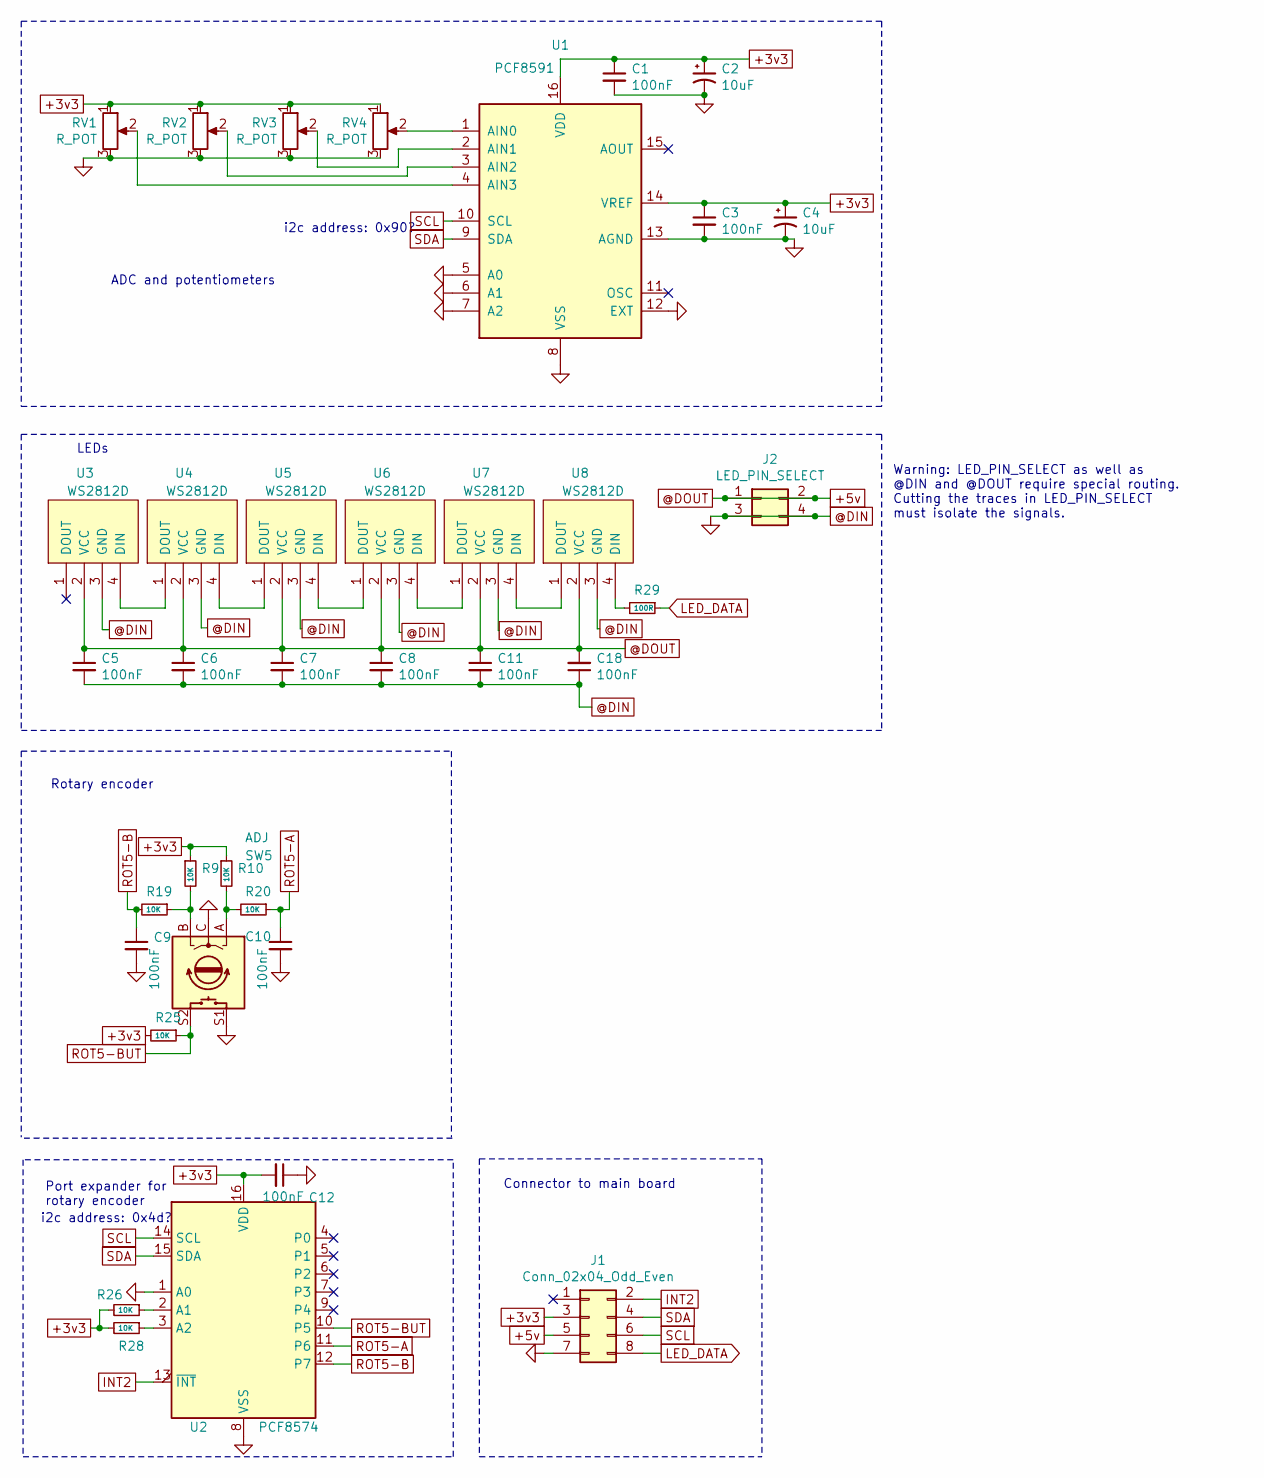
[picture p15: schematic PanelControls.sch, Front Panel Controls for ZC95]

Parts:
C1, C3, C5, C6, C7, C8, C9, C10, C11, C12, C18: 100nF; C_Disc_D3.0mm_W2.0mm_P2.50mm
C2, C4: 10uF; CP_Radial_D4.0mm_P2.00mm; LCSC C191532
J1: Conn_02x04_Odd_Even; IDC-Header_2x04_P2.54mm_Vertical
J2: LED_PIN_SELECT; PinHeader_2x02_P2.54mm_Vertical
R9, R10, R19, R20, R25, R26, R28: 10K; R_Axial_DIN0207_L6.3mm_D2.5mm_P7.62mm_Horizontal
R29: 100R; R_Axial_DIN0207_L6.3mm_D2.5mm_P7.62mm_Horizontal
RV1, RV2, RV3, RV4: R_POT; ALPSALPINE RK09L1140A2U
SW5: ADJ; BOURNS PEC11L-4125F-S0020
U1: PCF8591; SO-16_5.3x10.2mm_P1.27mm
U2: PCF8574; DIP-16_W7.62mm_LongPads
U3, U4, U5, U6, U7, U8: WS2812D; WS2812D-F5

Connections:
+3v3: C1.1, C2.1, C3.1, C4.1, C12.2, J1.3, R9.1, R10.1, R25.2, R26.2, R28.2, RV1.1, RV2.1, RV3.1, RV4.1, U1.14 (VREF), U1.16 (VDD), U2.16 (VDD)
+5v: C5.1, C6.1, C7.1, C8.1, C11.1, C18.2, J1.5, J2.1, J2.2, U3.2 (VCC), U4.2 (VCC), U5.2 (VCC), U6.2 (VCC), U7.2 (VCC), U8.2 (VCC)
@DIN: C1.2, C2.2, C3.2, C4.2, C5.2, C6.2, C7.2, C8.2, C9.2, C10.2, C11.2, C12.1, C18.1, J1.7, J2.3, J2.4, RV1.3, RV2.3, RV3.3, RV4.3, SW5.C, SW5.S1, U1.5 (A0), U1.6 (A1), U1.7 (A2), U1.8 (VSS), U1.12 (EXT), U1.13 (AGND), U2.1 (A0), U2.8 (VSS), U3.3 (GND), U4.3 (GND), U5.3 (GND), U6.3 (GND), U7.3 (GND), U8.3 (GND)
INT2: J1.2, U2.13 (~INT~)
LED_DATA: J1.8, R29.1
unnamed: R10.2, R20.2, SW5.A
unnamed: R9.2, R19.1, SW5.B
unnamed: R26.1, U2.2 (A1)
unnamed: R28.1, U2.3 (A2)
unnamed: R29.2, U8.4 (DIN)
unnamed: RV1.2, U1.4 (AIN3)
unnamed: RV2.2, U1.3 (AIN2)
unnamed: RV3.2, U1.2 (AIN1)
unnamed: RV4.2, U1.1 (AIN0)
unnamed: U3.4 (DIN), U4.1 (DOUT)
unnamed: U4.4 (DIN), U5.1 (DOUT)
unnamed: U5.4 (DIN), U6.1 (DOUT)
unnamed: U6.4 (DIN), U7.1 (DOUT)
unnamed: U7.4 (DIN), U8.1 (DOUT)
ROT5-A: C10.1, R20.1, U2.11 (P6)
ROT5-B: C9.1, R19.2, U2.12 (P7)
ROT5-BUT: R25.1, SW5.S2, U2.10 (P5)
SCL: J1.6, U1.10 (SCL), U2.14 (SCL)
SDA: J1.4, U1.9 (SDA), U2.15 (SDA)

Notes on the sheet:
LEDs
ADC and potentiometers
Port expander for rotary encoder
Rotary encoder
Connector to main board
i2c address: 0x90?
i2c address: 0x4d?
Warning: LED_PIN_SELECT as well as @DIN and @DOUT require special routing. Cutting the traces in LED_PIN_SELECT must isolate the signals.

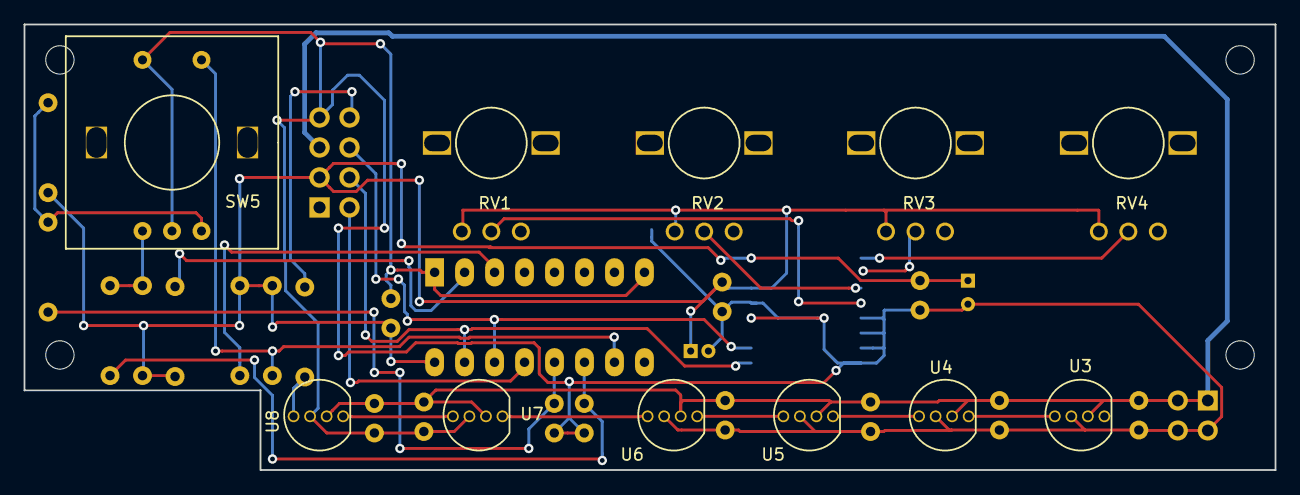
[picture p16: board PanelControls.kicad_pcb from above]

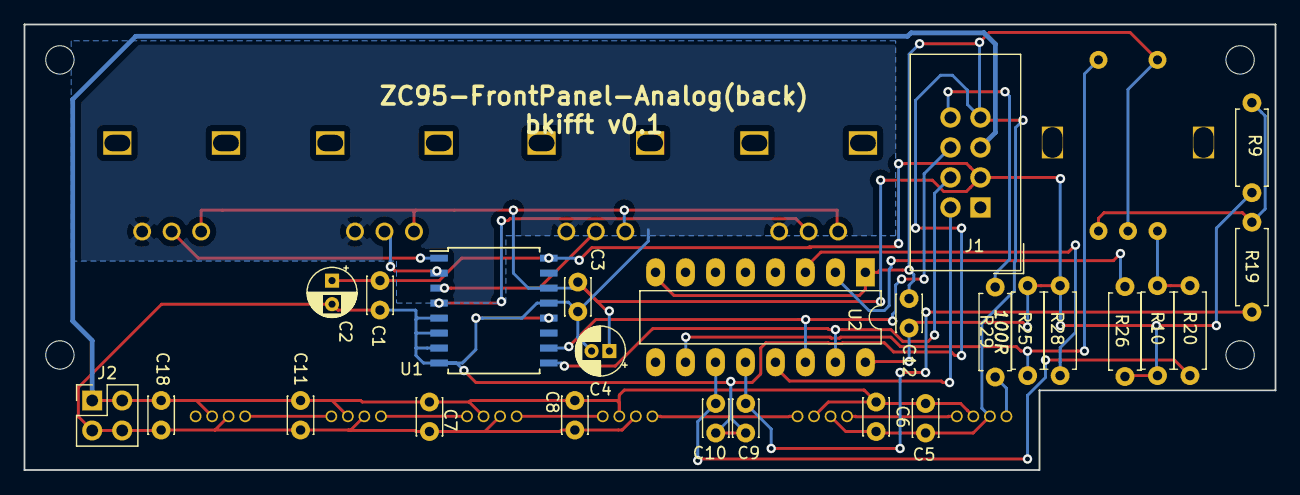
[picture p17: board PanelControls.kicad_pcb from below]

Board: 2 copper layers, 106.0 x 37.8 mm, 36 parts (25 on the bottom side), 24 nets.

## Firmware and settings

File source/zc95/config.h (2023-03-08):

#define PULSE_QUEUE_LENGTH 8  // queue size for pules sent from core0 to core1. Only used for audio pattern
                              // (maybe serial input in the future), where processing happens on core0

#define PATTERN_TEXT_OUTPUT_QUEUE_LENGTH 4 // Max number of queued text/debug messages from Core1 (so far just lua) to Core0

#define ZC624_ADDR                  0x10
#define EXT_INPUT_PORT_EXP_ADDR     0x21 // 3x I/O lines on front panel accesory port (p0-02), 4x for trigger inputs (p4-p7), 1x N/C (p3)
#define CONTROLS_PORT_EXP_ADDR      0x22 // 4x front pannel buttons (p0-p03), 3x I/O lines on expansion header J17 (p4-p6), 1x LCD backlight (p7)
#define FP_ANALOG_PORT_EXP_2_ADDR   0x26 // Port expander (U2) on the front pannel
#define AUDIO_DIGIPOT_ADDR          0x2C // Digital potentiometer used to set gain on audio board
#define ADC_ADDR                    0x48 // ADC on front pannel, used for power control dials
#define EEPROM_ADDR                 0x50 


#define I2C_PORT i2c0  // main i2c bus for port expanders + eeprom

// Set expected version for zc624 output module
#define ZC624_REQUIRED_MAJOR_VERION 0
#define ZC624_MIN_MINOR_VERION      3

// Versions for the GetVersion/VersionDetails message, but that's not used by anything yet
#define WEBSOCKET_API_VERION_MAJOR  1   // Increment on breaking change
#define WEBSOCKET_API_VERION_MINOR  0   // Increment non-breaking change

// The maximum length a web socket message can be in bytes
#define MAX_WS_MESSAGE_SIZE 200

// How many Lua instructions can be run on each Lua call. Protects against infinite loops locking up box.
#define LUA_MAX_INSTRUCTIONS 10000

// Other pins
#define PIN_LED           10 // ws2812 LED chain
#define PIN_CONTROLS_INT   7 // front pannel controls port expander interrupt pin
#define PIN_EXT_INPUT_INT 21 // external inputs port expander interrupt pin
#define PIN_433TX          3 // 433Mhz transmitter pin

#define PIN_FP_INT1       11 // front panel interupt 1 (U1) - 4x channel rot encoders
#define PIN_FP_INT2        6 // front panel interupt 2 (U2) - 5x rot enoder buttons & 1x adjust rot encoer (+ 1x unused line)


// Output board SPI
#define PIN_OUTPUT_BOARD_SPI_RX   12
#define PIN_OUTPUT_BOARD_SPI_SCK  14
#define PIN_OUTPUT_BOARD_SPI_TX   15
#define PIN_OUTPUT_BOARD_SPI_CSN  13

// For routines that don't care about pulse width and/or frequency, what to use
// TODO: maybe move these two to config options and save in EEPROM
#define DEFAULT_FREQ_HZ 150
#define DEFAULT_PULSE_WIDTH 150

#define TRIGGER_INPUT_DEBOUNCE_US 10000 // 10ms
#define RAMP_UP_TIME_MAXIMUM_SECS 30    // the maximum ramp up time that can be configured in seconds (0-255)

// For the time being, allowing more than one web socket connection is likely to cause all sorts of issues, 
// e.g. fighting for control over running routine, possibility to change a lua script whilst it's running, etc.
#define MAX_WEBSOCKET_CONNECTIONS 1 

// Note that just changing these two values would likely break everything
#define MAX_POWER_LEVEL 1000
#define MAX_CHANNELS 4


// SPI Defines
// We are going to use SPI 0, and allocate it to the following GPIO pins
// Pins can be changed, see the GPIO function select table in the datasheet for information on GPIO assignments
#define SPI_PORT spi0
#define PIN_MISO 16
#define PIN_CS   17
#define PIN_SCK  18
#define PIN_MOSI 19

// I2C defines
// This example will use I2C0 on GPIO8 (SDA) and GPIO9 (SCL) running at 400KHz.
// Pins can be changed, see the GPIO function select table in the datasheet for information on GPIO assignments
#define I2C_SDA 8
#define I2C_SCL 9

#define PIN_AUX_UART_TX 0
#define PIN_AUX_UART_RX 1

#define PIN_ACC_UART_TX 8
#define PIN_ACC_UART_RX 9

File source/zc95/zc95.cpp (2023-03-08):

/*
 * ZC95
 * Copyright (C) 2023  CrashOverride85
 * 
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
 * You should have received a copy of the GNU General Public License
 * along with this program.  If not, see <http://www.gnu.org/licenses/>
 */

#include <stdio.h>
#include <vector>
#include <string.h>
#include <inttypes.h>

#include "globals.h"
#include "config.h"
#include "git_version.h"

#include "pico/stdlib.h"
#include "hardware/spi.h"
#include "hardware/i2c.h"
#include "hardware/dma.h"
#include "hardware/pio.h"
#include "hardware/regs/rosc.h"
#include "hardware/regs/addressmap.h"
#include "hardware/adc.h"

#include "i2c_scan.h"
#include "CLedControl.h"
#include "CControlsPortExp.h"
#include "CExtInputPortExp.h"
#include "CEeprom.h"
#include "CSavedSettings.h"
#include "CTimingTest.h"
#include "CHwCheck.h"
#include "CAnalogueCapture.h"
#include "CBatteryGauge.h"
#include "CDebugOutput.h"

#include "AudioInput/CMCP4651.h"
#include "AudioInput/CAudio.h"

#include "display/CDisplay.h"
#include "display/CMainMenu.h"
#include "display/CMenuApMode.h"

#include "core1/Core1.h"
#include "core1/Core1Messages.h"
#include "core1/output/CChannelConfig.h"
#include "core1/routines/CRoutines.h"
#include "core1/CRoutineOutput.h"
#include "core1/CRoutineOutputCore1.h"

#include "RemoteAccess/CWifi.h"

#include "FpKnobs/CFrontPanel.h"
#include "ECButtons.h"

CControlsPortExp controls = CControlsPortExp(CONTROLS_PORT_EXP_ADDR);
CExtInputPortExp *ext_input = NULL;
CEeprom eeprom = CEeprom(I2C_PORT, EEPROM_ADDR);
CFrontPanel *_front_pannel = NULL;
CAnalogueCapture analogueCapture;
CBatteryGauge batteryGauge;
CMCP4651 audio_gain;
CAudio audio(&analogueCapture, &audio_gain, &controls);
CWifi *wifi = NULL;

void gpio_callback(uint gpio, uint32_t events) 
{
    if (gpio == PIN_CONTROLS_INT)
    {
        controls.interrupt();
    }
    else if (gpio == PIN_EXT_INPUT_INT)
    {
        if (ext_input)
            ext_input->interrupt();
    }
    else if (gpio == PIN_FP_INT1)
    {
        if (_front_pannel != NULL)
            _front_pannel->interupt(CFrontPanel::port_exp::U1);
    }
    else if (gpio == PIN_FP_INT2)
    {
        if (_front_pannel != NULL)
            _front_pannel->interupt(CFrontPanel::port_exp::U2);
    }
}

void check_button(CControlsPortExp *controls, CMenu *current_menu, Button button)
{
    bool new_state = false;
    if (controls->has_button_state_changed(button, &new_state))
    {
        if (new_state)
            current_menu->button_pressed(button);
        else
            current_menu->button_released(button);
    }
}

void process_front_pannel_input(CControlsPortExp *controls, CMenu *current_menu)
{
    check_button(controls, current_menu, Button::A);
    check_button(controls, current_menu, Button::B);
    check_button(controls, current_menu, Button::C);
    check_button(controls, current_menu, Button::D);
}

void update_power_levels_from_front_pannel(CRoutineOutput *routine_output)
{
    for (int chan=0; chan < MAX_CHANNELS; chan++)
    {
        uint16_t fp_power = _front_pannel->get_channel_power_level(chan);
        routine_output->set_front_panel_power(chan, fp_power);   
    }
}

/* Stolen from https://www.raspberrypi.org/forums/viewtopic.php?t=302960
 * "Random number generator - an example" by bgolab Feb 2021 */
void seed_random_from_rosc()
{
  uint32_t random = 0x811c9dc5;
  uint8_t next_byte = 0;
  volatile uint32_t *rnd_reg = (uint32_t *)(ROSC_BASE + ROSC_RANDOMBIT_OFFSET);

  for (int i = 0; i < 16; i++) {
    for (int k = 0; k < 8; k++) {
      next_byte = (next_byte << 1) | (*rnd_reg & 1);
    }

    random ^= next_byte;
    random *= 0x01000193;
  }

  srand(random);
} 

int main()
{
    // Serial going to 3.5mm aux socket
    gpio_set_function(PIN_AUX_UART_TX, GPIO_FUNC_UART);
    gpio_set_function(PIN_AUX_UART_RX, GPIO_FUNC_UART);
    
    // Serial on acc port
    gpio_set_function(PIN_ACC_UART_TX, GPIO_FUNC_UART);
    gpio_set_function(PIN_ACC_UART_RX, GPIO_FUNC_UART);    
    
    // For now, until settings loaded from eeprom, send debugging info to accessory port
    CDebugOutput::set_debug_destination(CDebugOutput::debug_dest_t::ACC);
    
    adc_init();
    messages_init();

    printf("\n\nZC95 Startup, firmware version: %s\n", kGitHash);

    mutex_init(&gI2cMutex);

    // I2C Initialisation
    i2c_init(i2c_default, 100 * 1000);
    gpio_set_function(PICO_DEFAULT_I2C_SDA_PIN, GPIO_FUNC_I2C);
    gpio_set_function(PICO_DEFAULT_I2C_SCL_PIN, GPIO_FUNC_I2C);
    gpio_pull_up(PICO_DEFAULT_I2C_SDA_PIN);
    gpio_pull_up(PICO_DEFAULT_I2C_SCL_PIN);

    CHwCheck hw_check(&batteryGauge);
    hw_check.check_part1(); // If a fault is found, this never returns
    audio.set_audio_digipot_found(hw_check.audio_digipot_found());
    
    // switch off backlight until init done
    controls.set_lcd_backlight(false);

    // Make sure there is some semi-random-ish data available
    seed_random_from_rosc();

    // Note eeprom ic is on i2c bus
    sleep_ms(100); // wait for eeprom to be ready
    CSavedSettings settings = CSavedSettings(&eeprom);
    g_SavedSettings = &settings;

    // Configure AUX port for serial or audio use
    if (settings.get_aux_port_use() == CSavedSettings::setting_aux_port_use::AUDIO)
    {
        //sleep_ms(100); // wait for eeprom to be ready
        controls.audio_input_enable(true);
    }
    else
    {
        controls.audio_input_enable(false);
    }

    CDebugOutput::set_debug_destination_from_settings(&settings);

    _front_pannel = new CFrontPanel(&settings);

    // Front pannel LEDs - give some feedback we're powering up (display takes almost second to appear)
    CLedControl led = CLedControl(PIN_LED, &settings);
    led.init();
    led.set_all_led_colour(LedColour::Purple);
    led.loop();

    // front panel push buttons on controls port expander
    gpio_init(PIN_CONTROLS_INT);
    gpio_set_dir(PIN_CONTROLS_INT, GPIO_IN);
    gpio_set_irq_enabled_with_callback(PIN_CONTROLS_INT, GPIO_IRQ_EDGE_FALL, true, &gpio_callback);
    controls.clear_input();
    controls.process(true);

    // Front pannel
    gpio_set_irq_enabled_with_callback(PIN_FP_INT1, GPIO_IRQ_EDGE_FALL, true, &gpio_callback);
    gpio_set_irq_enabled_with_callback(PIN_FP_INT2, GPIO_IRQ_EDGE_FALL, true, &gpio_callback);
  
    // Configure SPI display
    CDisplay display = CDisplay();
    display.init(); // This takes some time - not far off a second

    // Get list of available patterns / routines
    std::vector<CRoutines::Routine> routines;
    CRoutines::get_routines(&routines);
   
    hw_check.check_part2(&led, &controls); // If a fault is found, this never returns

    // Queue used for pulses from audio processing on core0 being sent to core1 for output
    for (uint8_t channel = 0; channel < MAX_CHANNELS; channel++)
        queue_init(&gPulseQueue[channel], sizeof(pulse_message_t), PULSE_QUEUE_LENGTH);

    // Queue used for routines (so far just Lua) running on Core1 to send debug messages (via print())
    // out over a websocket connection, if running via RemoteAccess
    queue_init(&gPatternTextOutputQueue, sizeof(pattern_text_output_t), PATTERN_TEXT_OUTPUT_QUEUE_LENGTH);

    // Load/set gain, mic preamp, etc., from eeprom
    audio.init(&settings, &display);

    analogueCapture.start();

    led.set_all_led_colour(LedColour::Black);

    sleep_ms(100);

    core1_start(&routines, &settings);
    CRoutineOutput* routine_output = new CRoutineOutputCore1(&display, &led, &ext_input);

    audio.set_routine_output(routine_output);
    wifi = new CWifi(&analogueCapture, routine_output, &routines);  

    // Configure port expander used for external inputs (accessory & trigger sockets)
    ext_input = new CExtInputPortExp(EXT_INPUT_PORT_EXP_ADDR, &led, routine_output);
    gpio_init(PIN_EXT_INPUT_INT);
    gpio_set_dir(PIN_EXT_INPUT_INT, GPIO_IN);
    gpio_set_irq_enabled_with_callback(PIN_EXT_INPUT_INT, GPIO_IRQ_EDGE_FALL, true, &gpio_callback);
    ext_input->clear_input();
    ext_input->process(true);


    CMainMenu routine_selection = CMainMenu(&display, &routines, &controls, &settings, routine_output, &hw_check, &audio, &analogueCapture, wifi);
    routine_selection.show();
    CMenu *current_menu = &routine_selection;
    display.set_current_menu(current_menu);

    uint64_t start = time_us_64();
    led.loop();
    controls.set_lcd_backlight(true);
    uint64_t last_analog_check = 0;
    display.set_battery_percentage(batteryGauge.get_battery_percentage());

    while (1) 
    {
        uint64_t loop_start = time_us_64();
        wifi->loop();

        display.update();
        process_front_pannel_input(&controls, current_menu);

        int8_t adj = _front_pannel->get_adjust_control_change();
        if (adj && current_menu)
        {
            current_menu->adjust_rotary_encoder_change(adj);
        }

        if (time_us_64() > last_analog_check + 50000)
        {
            _front_pannel->process(true);
            last_analog_check = time_us_64();
        }
    
        update_power_levels_from_front_pannel(routine_output);
        if (time_us_64() - start > 1000000) // every second
        {
            start = time_us_64();
            controls.process(true);   // ~215us
            ext_input->process(true); // ~215us
            led.loop(true); // ~55us    

            uint64_t timenow = time_us_64();
            uint8_t batt_percentage = batteryGauge.get_battery_percentage();
            printf("Loop time: %" PRId64 ", batt: %d\n", timenow - loop_start, batt_percentage);
            display.set_battery_percentage(batt_percentage);
        }
        else
        {
            ext_input->process(false);
            controls.process(false);
            _front_pannel->process(false);     
         //   hw_check.process();
        }

        routine_output->loop();
        led.loop();
        analogueCapture.process();
        audio.process();

        if (audio.is_audio_update_available(true))
        {
            display.set_update_required();
        }

        if (analogueCapture.new_battery_readings_available())
        {
            uint8_t readings_count = 0;
            uint8_t *readings = analogueCapture.get_battery_readings(&readings_count);
            batteryGauge.add_raw_adc_readings(readings, readings_count);
        }

        if (gFatalError)
        {
            routine_output->stop_routine();
            hw_check.die(&led, gErrorString); // never returns
        }
    }

    return 0;
}

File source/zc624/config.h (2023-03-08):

#ifndef _CCONFIG_H
#define _CCONFIG_H

// SPI Defines
// We are going to use SPI 0, and allocate it to the following GPIO pins
/*

    SPIx_SCK = SCK
    SPIx_TX = MOSI
    SPIx_RX = MISO
*/

#define SPI_PORT spi0
#define PIN_SPI_MOSI 16 // RX
#define PIN_SPI_CS   17
#define PIN_SPI_SCK  18
#define PIN_SPI_MISO 19 // TX
#define SPI_BAUD_RATE 500000


// I2C defines

// For connection to on board DAC (so we are i2c master)
#define I2C_PORT_PER i2c1
#define I2C_SDA_PER 2
#define I2C_SCL_PER 3

#define DAC_ADDRESS 0x60

// For connection to main board (so we are i2c slave)
#define I2C_PORT_SLAVE i2c0
#define I2C_SDA_SLAVE 4
#define I2C_SCL_SLAVE 5
#define ZC624_ADDR  0x10 // our address


#define DEVICE_TYPE   624
#define VERSION_MAJOR   0
#define VERSION_MINOR   3




#define PIN_9V_ENABLE   14

#define PIN_CHAN1_GATE_A 6
#define PIN_CHAN1_GATE_B 7

#define PIN_CHAN2_GATE_A 8
#define PIN_CHAN2_GATE_B 9

#define PIN_CHAN3_GATE_A 10
#define PIN_CHAN3_GATE_B 11

#define PIN_CHAN4_GATE_A 12
#define PIN_CHAN4_GATE_B 13

#endif

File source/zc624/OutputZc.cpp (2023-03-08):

#include "config.h"
#include <inttypes.h>
#include <stdio.h>
#include <stdlib.h>
#include "pico/stdlib.h"
#include "pico/multicore.h"

#include "hardware/i2c.h"
#include "hardware/pio.h"
#include "hardware/adc.h"
#include "hardware/spi.h"

#include "CMCP4728.h"
#include "COutput.h"
#include "CMessageProcess.h"
#include "messages.h"
#include "CI2cSlave.h"
#include "git_version.h"

/*
 * Core0 handles incoming SPI messages, and output/generation (via pio) of signals to drive the FETs. Any 
 * messages received which are to change the power level are passed to core1.
 * Core1 deals with I2C comms to set power levels, as this can be a little slow (~200us per power change)
 */

void i2c_scan();
void core1_entry();

CI2cSlave *i2c_slave;

int main()
{
    stdio_init_all();
    adc_init();
    
    printf("ZC624 startup, firmware version: %s\n", kGitHash);
    i2c_slave = new CI2cSlave();

    // I2C Initialisation as master (connected to DAC). Using it at 400Khz.
    i2c_init(I2C_PORT_PER, 400*1000);
    
    gpio_set_function(I2C_SDA_PER, GPIO_FUNC_I2C);
    gpio_set_function(I2C_SCL_PER, GPIO_FUNC_I2C);
    gpio_pull_up(I2C_SDA_PER);
    gpio_pull_up(I2C_SCL_PER);

    i2c_scan();
    multicore_reset_core1();
    multicore_launch_core1(core1_entry);

    // Control of 4x output channels
    COutput output = COutput(pio0, i2c_slave);

    // Comms to main board
    CMessageProcess spi_message_process = CMessageProcess(&output);
    spi_message_process.init();
    uint64_t loop_start = time_us_64();
    uint64_t readable=0;
    uint64_t unreadable=0;

    while(1)
    {
        if (spi_is_readable(spi0))
        {
            spi_message_process.loop();
            readable++;
        }
        else
        {
            unreadable++;
        }
        
        if (time_us_64() - loop_start > 1000000)
        {
            // printf("running... (readable=%" PRIu64 ", unreadable=%" PRIu64 "\n", readable, unreadable);
            loop_start = time_us_64();
            readable=0;
            unreadable=0;
        }

        output.loop();

        if (i2c_slave->get_value(CI2cSlave::reg::OverallStatus) == CI2cSlave::status::Fault)
        {
            printf("HALT.\n");
            while(1);
        } 
    }

    return 0;
}

void core1_entry() 
{
    printf("core1_entry()\n");
    CMCP4728 dac = CMCP4728(I2C_PORT_PER, DAC_ADDRESS);

    while(1)
    {
        message msg;
        msg.msg32 = multicore_fifo_pop_blocking();
        
        switch(msg.msg8[0])
        {
            case MESSAGE_SET_DAC_POWER:
            {
                uint8_t channel = msg.msg8[1];
                uint16_t value = msg.msg8[2];
                value |= msg.msg8[3] << 8;
                // printf("set power chan %d to %d\n", channel, value);
                dac.set_channel_value((CDac::dac_channel)channel, value);
            }
                break;

            default:
                printf("Unknown message type received: %d\n", msg.msg8[0]);
                break;
        }
    }
}

// I2C reserves some addresses for special purposes. We exclude these from the scan.
// These are any addresses of the form 000 0xxx or 111 1xxx
bool reserved_addr(uint8_t addr) 
{
    return (addr & 0x78) == 0 || (addr & 0x78) == 0x78;
}

void i2c_scan()
{
    for (int addr = 0; addr < (1 << 7); ++addr) 
    {
        if (addr % 16 == 0) 
        {
            printf("%02x ", addr);
        }

        // Perform a 1-byte dummy read from the probe address. If a slave
        // acknowledges this address, the function returns the number of bytes
        // transferred. If the address byte is ignored, the function returns
        // -1.

        // Skip over any reserved addresses.
        int ret;
        uint8_t rxdata;
        if (reserved_addr(addr))
            ret = PICO_ERROR_GENERIC;
        else
            ret = i2c_read_blocking(I2C_PORT_PER, addr, &rxdata, 1, false);

        printf(ret < 0 ? "." : "@");
        printf(addr % 16 == 15 ? "\n" : "  ");
    }
    printf("Done.\n");
}

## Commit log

2022-06-04 initial changes FrontPanel
    [PanelControls.kicad_pcb, PanelControls.sch]
2022-06-04 initial version
    [picoprobe.kicad_pcb, picoprobe.sch]

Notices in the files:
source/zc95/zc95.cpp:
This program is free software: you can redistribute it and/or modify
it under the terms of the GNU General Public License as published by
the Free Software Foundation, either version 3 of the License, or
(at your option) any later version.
